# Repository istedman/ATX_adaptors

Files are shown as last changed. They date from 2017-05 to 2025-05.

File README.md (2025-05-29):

# ATX_adaptors
ATX power adaptors for the Amiga and other retro computers. Allows easy access to an ATX replacement supply. The +5V, +12V and -12C supplies are available on screw terminal connectors for easy retro fit. The Multi-purpose design can also supply -5V, the 50/60Hz tick signal and a Power_good signal.

The schematics and PCB files are included here in Eagle CAD format, V7 or later is required to open the files.

The adaptors use a Microchip PIC10F200 microcontroller to debounce the switch and to turn on/off the power. The same micro is used to provide a 50/60Hz 'tick' signal. Accuracy was ~0.5Hz using internal oscillator. A Tag-connect MCP2030 is required to program the device. The ATX_PICV1.zip file has the software. MplabX and XC8 compiler required to rebuild. A hex file is within the archive.

# 2021 Update

I'm discontinuing sales of all Amiga related projects. Reduced order volumes and extra issues with order post Brexit have not made it viable to continue.
All information, including BOMs, Gerbers and notes are now in the repository, if you want to build your own.

# 2025 update

I have re-exported the BOM data from the Excel originals. The part numbers are those from Quick-teck, who used to manufacture these boards for me. It's not a complicated design.

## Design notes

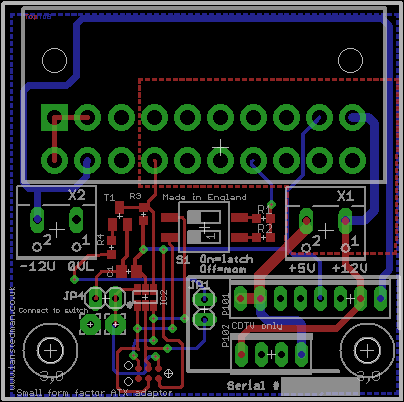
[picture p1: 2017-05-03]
Small-form-factor-picoPSU-PCB.png

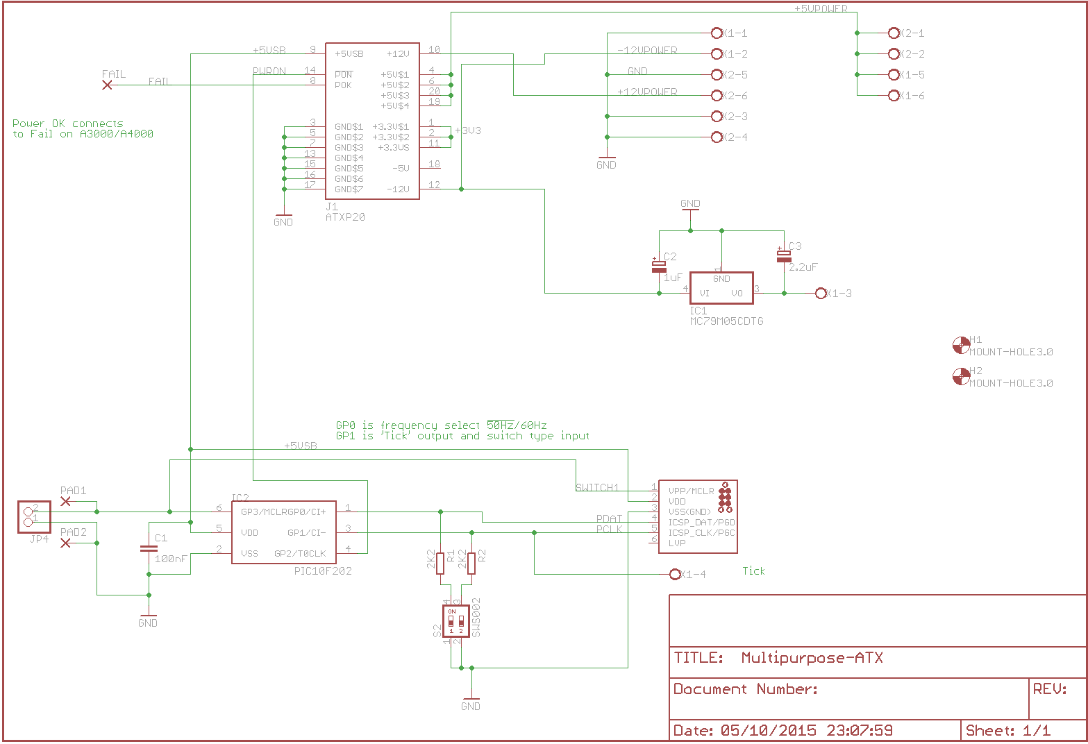
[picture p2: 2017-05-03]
Multipurpose-Bigbox-ATX-SCH.png

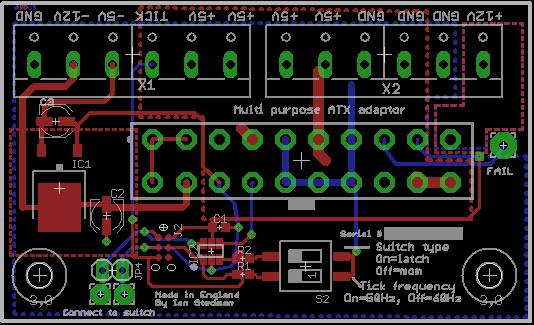
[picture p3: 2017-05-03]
Multipurpose-Bigbox-ATX-PCB.png

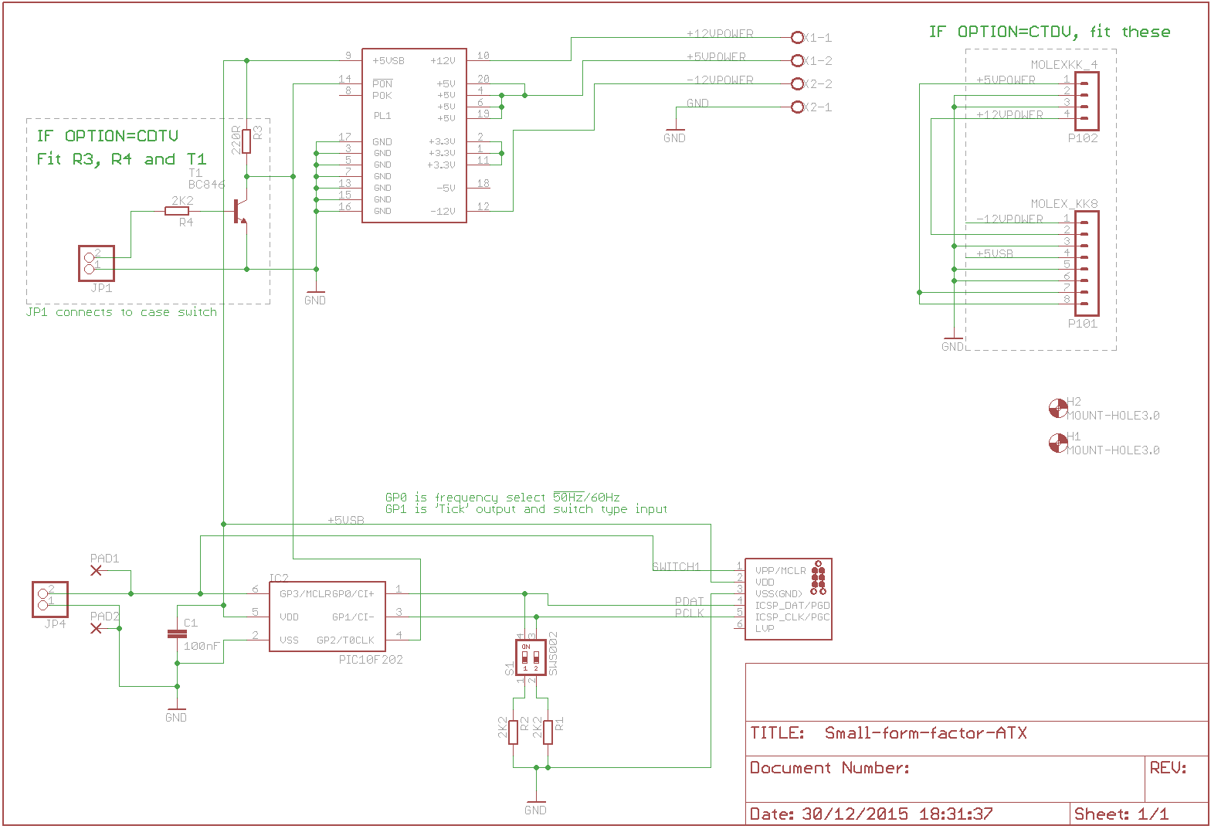
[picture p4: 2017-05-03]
Small-form-factor-picoPSU-SCH.png

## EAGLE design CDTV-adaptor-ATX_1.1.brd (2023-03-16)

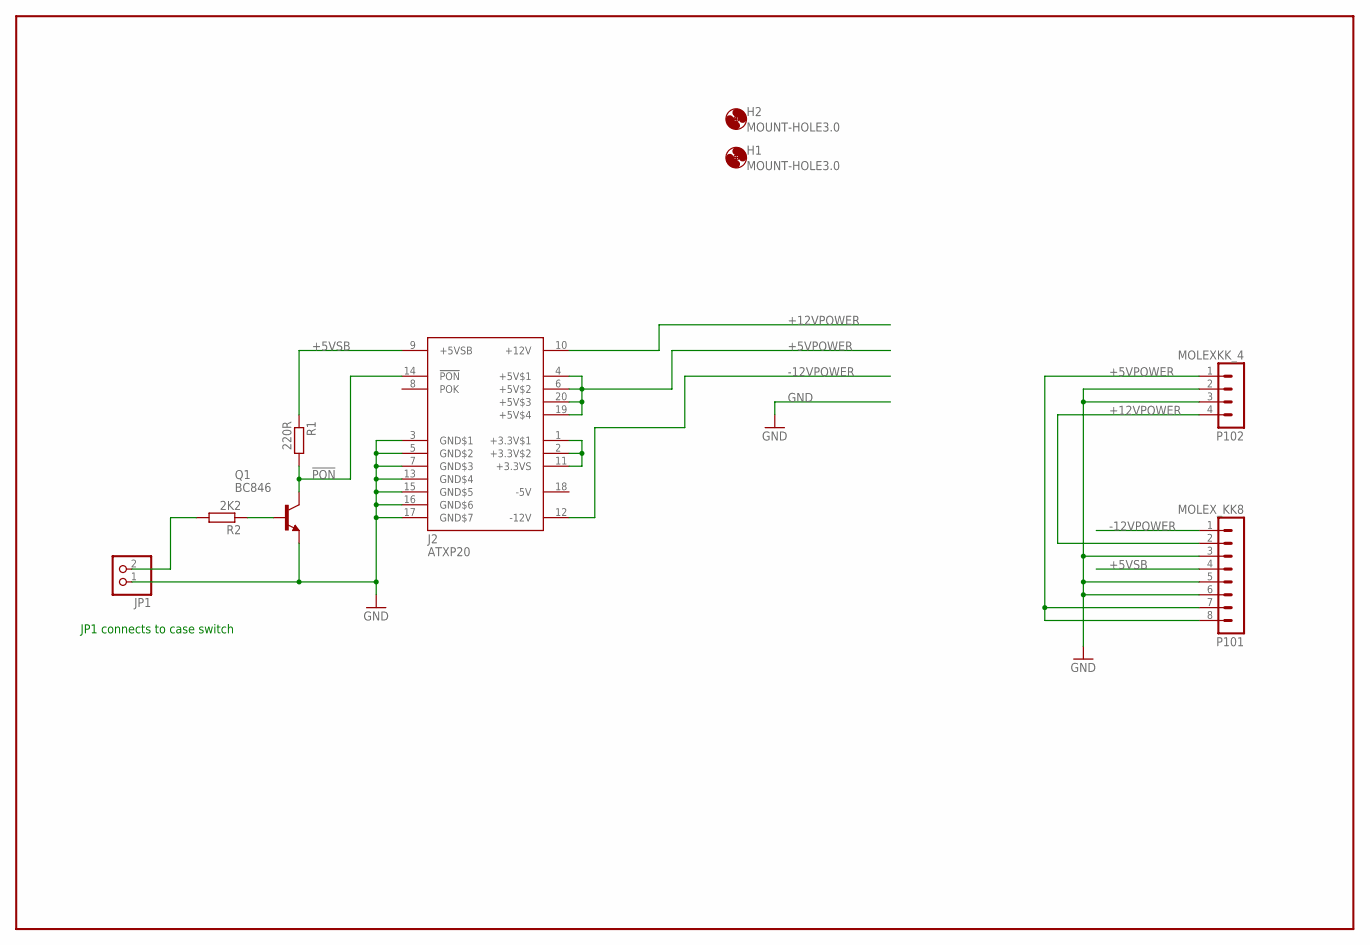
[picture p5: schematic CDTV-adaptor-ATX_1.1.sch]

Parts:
H1, H2: MOUNT-HOLE3.0; 3,0
J2: ATXP20; MOLEX39281203
JP1: PINHD-1X2; 1X02
P101: MOLEX_KK8
P102: MOLEXKK_4; MA04-1
Q1: BC846; SOT23
R1: 220R; R0603
R2: 2K2; R0603

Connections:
!PON: J2.14 (!PON), Q1.3 (C), R1.2
+5VPOWER: J2.4 (+5V$1), J2.6 (+5V$2), J2.19 (+5V$4), J2.20 (+5V$3), P101.7, P101.8, P102.1
+5VSB: J2.9 (+5VSB), P101.4, R1.1
+12VPOWER: J2.10 (+12V), P101.2, P102.4
-5V: J2.18 (-5V)
-12VPOWER: J2.12 (-12V), P101.1
GND: J2.3 (GND$1), J2.5 (GND$2), J2.7 (GND$3), J2.13 (GND$4), J2.15 (GND$5), J2.16 (GND$6), J2.17 (GND$7), JP1.1, P101.3, P101.5, P101.6, P102.2, P102.3, Q1.2 (E)
unnamed: Q1.1 (B), R2.1
unnamed: J2.1 (+3.3V$1), J2.2 (+3.3V$2), J2.11 (+3.3VS)
SWITCH: JP1.2, R2.2

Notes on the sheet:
JP1 connects to case switch

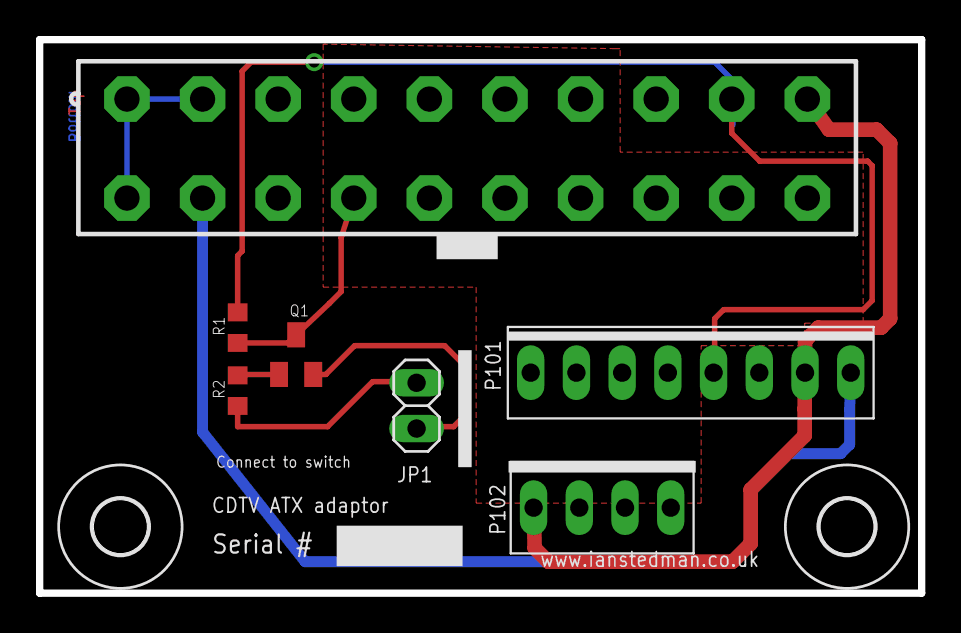
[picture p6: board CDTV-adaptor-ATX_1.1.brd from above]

Board: 2 copper layers, 49.0 x 30.8 mm, 9 parts (0 on the bottom side), 9 nets.

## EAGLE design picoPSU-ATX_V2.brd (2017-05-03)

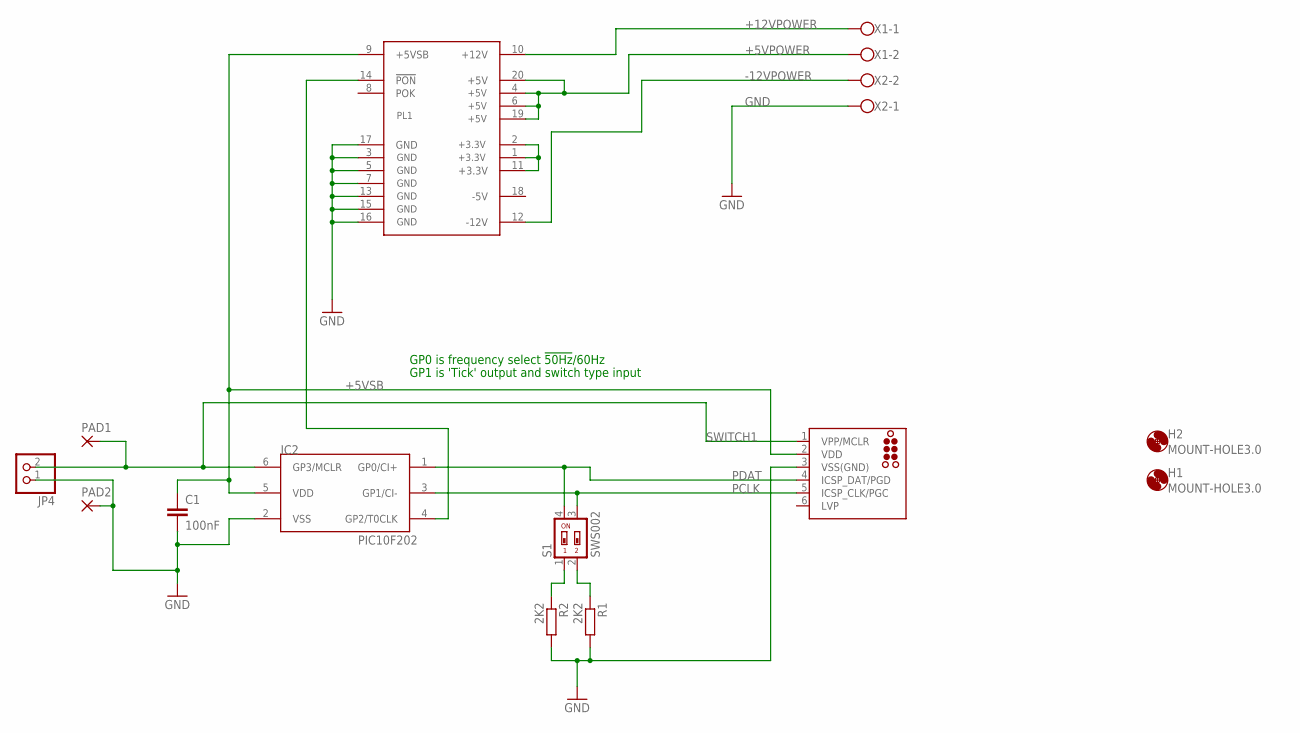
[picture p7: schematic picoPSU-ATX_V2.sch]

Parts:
C1: 100nF; C0805
H1, H2: MOUNT-HOLE3.0; 3,0
IC2: PIC10F202; SOT23-6
J1: TC2030-MCP-NL
JP4: PINHD-1X2; 1X02
PAD1, PAD2: 2,54/1,1
PL1: MOLEX39-30-1200; ATX_RIGHT
R1, R2: 2K2; R0603
S1: SWS002; SMS-002
X1, X2: W237-102

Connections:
+5VPOWER: PL1.4 (+5V), PL1.6 (+5V), PL1.19 (+5V), PL1.20 (+5V), X1.2
+5VSB: C1.1, IC2.5 (VDD), J1.2 (VDD), PL1.9 (+5VSB)
+12VPOWER: PL1.10 (+12V), X1.1
-12VPOWER: PL1.12 (-12V), X2.2
GND: C1.2, IC2.2 (VSS), J1.3 (VSS(GND)), JP4.1, PAD2.1, PL1.3 (GND), PL1.5 (GND), PL1.7 (GND), PL1.13 (GND), PL1.15 (GND), PL1.16 (GND), PL1.17 (GND), R1.2, R2.2, X2.1
unnamed: R2.1, S1.1
unnamed: R1.1, S1.2
unnamed: PL1.1 (+3.3V), PL1.2 (+3.3V), PL1.11 (+3.3V)
PCLK: IC2.3 (GP1/CI-), J1.5 (ICSP_CLK/PGC), S1.3
PDAT: IC2.1 (GP0/CI+), J1.4 (ICSP_DAT/PGD), S1.4
PWRON: IC2.4 (GP2/T0CLK), PL1.14 (!PON)
SWITCH1: IC2.6 (GP3/MCLR), J1.1 (VPP/MCLR), JP4.2, PAD1.1

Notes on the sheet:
GP0 is frequency select !50Hz!/60Hz
GP1 is 'Tick' output and switch type input

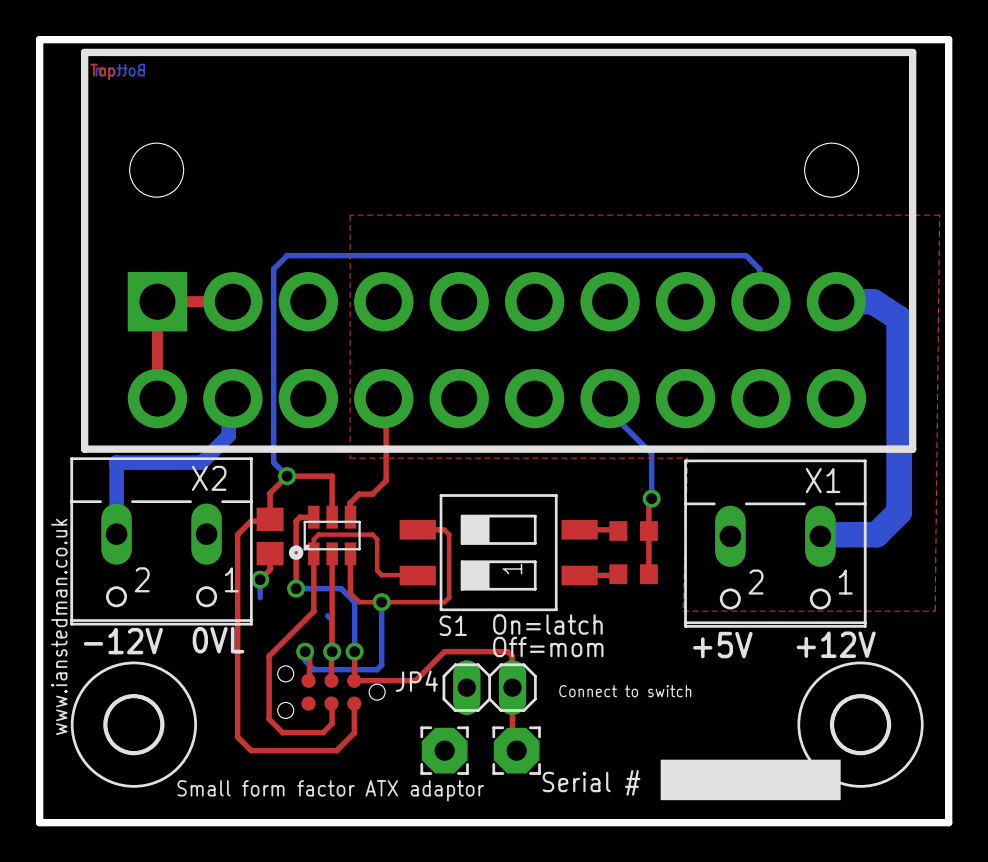
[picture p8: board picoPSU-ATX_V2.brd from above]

Board: 2 copper layers, 50.5 x 43.5 mm, 14 parts (0 on the bottom side), 12 nets.

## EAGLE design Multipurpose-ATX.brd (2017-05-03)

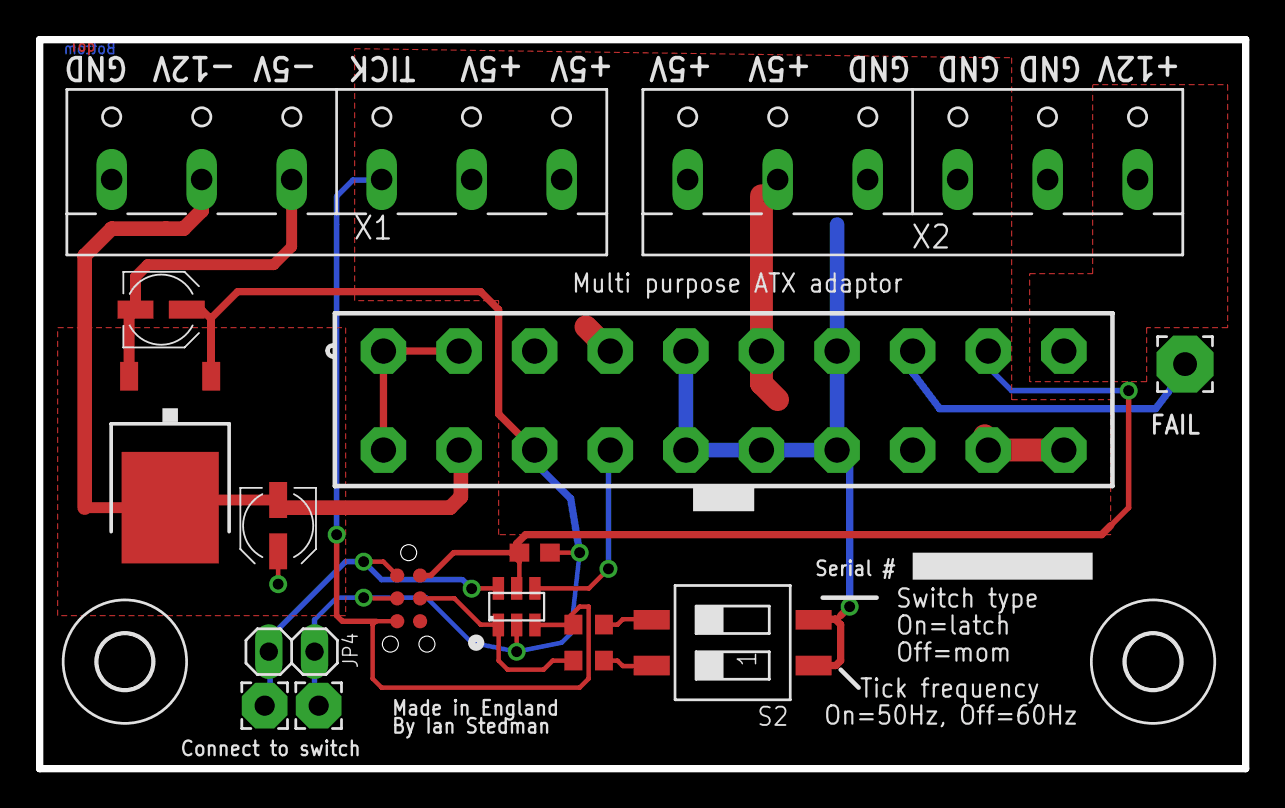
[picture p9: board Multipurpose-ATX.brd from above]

Board: 2 copper layers, 67.0 x 40.5 mm, 18 parts (0 on the bottom side), 14 nets.

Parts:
C1: 100nF; C0603
C2: 1uF; UD-4X5,8_NICHICON
C3: 2.2uF; UD-4X5,8_NICHICON
FAIL: 3,17/1,3
H1, H2: MOUNT-HOLE3.0; 3,0
IC1: MC79M05CDTG; DPACK_3
IC2: PIC10F202; SOT23-6
J1: ATXP20; MOLEX39281203
J2: TC2030-MCP-NL
JP4: 1X02
PAD1, PAD2: 2,54/1,1
R1, R2: 2K2; R0603
S2: SWS002; SMS-002
X1, X2: W237-6

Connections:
+3V3: J1.1, J1.2, J1.11
+5VPOWER: J1.4, J1.6, J1.19, J1.20, X1.5, X1.6, X2.1, X2.2
+5VSB: C1.1, IC2.5, J1.9, J2.2
+12VPOWER: J1.10, X2.6
-12VPOWER: C2.-, IC1.4, J1.12, X1.2
FAIL: FAIL.1, J1.8
GND: C1.2, C2.+, C3.+, IC1.1, IC2.2, J1.3, J1.5, J1.7, J1.13, J1.15, J1.16, J1.17, J2.3, JP4.1, PAD2.1, S2.1, S2.2, X1.1, X2.3, X2.4, X2.5
unnamed: R2.2, S2.3
unnamed: R1.2, S2.4
unnamed: C3.-, IC1.3, X1.3
PCLK: IC2.3, J2.5, R2.1, X1.4
PDAT: IC2.1, J2.4, R1.1
PWRON: IC2.4, J1.14
SWITCH1: IC2.6, J2.1, JP4.2, PAD1.1

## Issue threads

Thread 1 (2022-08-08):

Mission BOM files

kavanoz64, 2022-08-08:
BOM HTML files have links to actual pages, which are not included in the repository. Could you please upload the source Excel BOM file?
<link rel=File-List href="Original_BigBox_BOM_2019_files/filelist.xml">
<link id="shLink" href="Original_BigBox_BOM_2019_files/sheet001.htm">
<link id="shLink" href="Original_BigBox_BOM_2019_files/sheet002.htm">
<link id="shLink" href="Original_BigBox_BOM_2019_files/sheet003.htm">

Thanks

istedman, 2025-05-29:
Fixed the issue with the latest export.

Closed 2025-05-29.

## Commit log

2017-08-01 Add files via upload
    Gerber files for the PCBs, these are the files I send to the PCB vendor.
2023-03-16 Add files via upload
    CDTV adaptor Gerber files
2023-03-16 Add files via upload
    Eagle CAD 7.7 original files for the CDTV adaptor
    [CDTV-adaptor-ATX_1.1.brd, CDTV-adaptor-ATX_1.1.sch]

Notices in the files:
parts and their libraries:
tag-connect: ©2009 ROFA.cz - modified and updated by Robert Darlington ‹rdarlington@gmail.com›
